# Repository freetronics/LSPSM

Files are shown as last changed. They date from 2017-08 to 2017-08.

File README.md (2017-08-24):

Freetronics LibreSat Power Supply Module
========================================
Copyright 2013 Freetronics Pty Ltd  
Freetronics site:  www.freetronics.com.au  
Freetronics email: info@freetronics.com.au  

FIXME

Features:

 * FIXME

More information is available at:

  http://www.freetronics.com.au/lspsm

INSTALLATION
------------
The design is saved as an EAGLE project. EAGLE PCB design software is
available from www.cadsoftusa.com free for non-commercial use. To use
this project download it and place the directory containing these files
into the "eagle" directory on your computer. Then open EAGLE and
navigate to the project.

DISTRIBUTION
------------
The specific terms of distribution of this project are governed by the
license referenced below.

LICENSE
-------
Licensed under the TAPR Open Hardware License (www.tapr.org/OHL).
The "license" folder within this repository also contains a copy of
this license in plain text format.

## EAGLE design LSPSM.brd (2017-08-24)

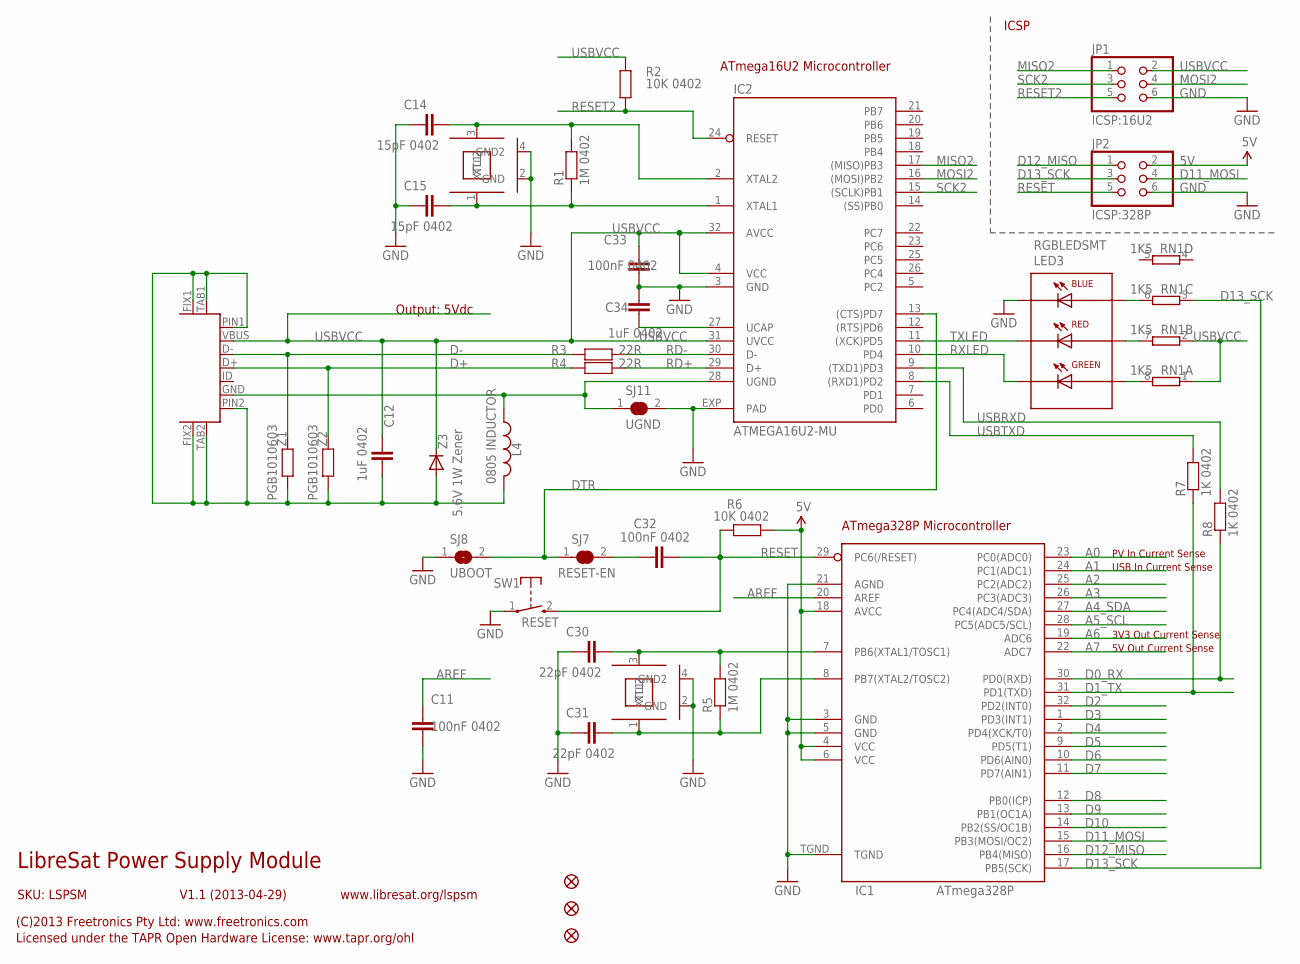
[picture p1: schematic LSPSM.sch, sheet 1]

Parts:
C11, C32, C33: 100nF 0402; 0402C
C12, C34: 1uF 0402; 0402C
C14, C15: 15pF 0402; 0402C
C30, C31: 22pF 0402; 0402C
FID1, FID2, FID3: FIDUCIAL1X2.5; FIDUCIAL-1X2.5
IC1: ATmega328P; MLF32
IC2: ATMEGA16U2-MU; ATMEL_QFN32
JP1: ICSP:16U2; 2X03
JP2: ICSP:328P; 2X03
L4: 0805 INDUCTOR; 0805-LARGE
LED3: RGBLEDSMT; 19-337
R1, R5: 1M 0402; 0402
R2, R6: 10K 0402; 0402
R3, R4: 22R; 0402
R7, R8: 1K 0402; 0402
RN1: 1K5; CAY16
S1: USB-6PSMT; USB-MICROB-MB05PMXX
SJ7: RESET-EN; 0402SJC
SJ8: UBOOT; 0402SJO
SJ11: UGND; 0402SJC
SW1: RESET; TACTILE_SWITCH_SMD_2PIN_TINY
XTL1, XTL2: 16MHz; CRYSTAL-SMD-3X2
Z1, Z2: PGB1010603; 0603
Z3: 5.6V 1W Zener; SMA-DIODE

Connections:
5V: IC1.4 (VCC), IC1.6 (VCC), IC1.18 (AVCC), JP2.2, R6.2; also elsewhere on the board
A0: IC1.23 (PC0(ADC0)); also elsewhere on the board
A1: IC1.24 (PC1(ADC1)); also elsewhere on the board
A2: IC1.25 (PC2(ADC2)); also elsewhere on the board
A3: IC1.26 (PC3(ADC3)); also elsewhere on the board
A4_SDA: IC1.27 (PC4(ADC4/SDA)); also elsewhere on the board
A5_SCL: IC1.28 (PC5(ADC5/SCL)); also elsewhere on the board
A6: IC1.19 (ADC6); also elsewhere on the board
A7: IC1.22 (ADC7); also elsewhere on the board
AREF: C11.1, IC1.20 (AREF); also elsewhere on the board
D0_RX: IC1.30 (PD0(RXD)), R8.1; also elsewhere on the board
D1_TX: IC1.31 (PD1(TXD)), R7.1; also elsewhere on the board
D2: IC1.32 (PD2(INT0)); also elsewhere on the board
D3: IC1.1 (PD3(INT1)); also elsewhere on the board
D4: IC1.2 (PD4(XCK/T0)); also elsewhere on the board
D5: IC1.9 (PD5(T1)); also elsewhere on the board
D6: IC1.10 (PD6(AIN0)); also elsewhere on the board
D7: IC1.11 (PD7(AIN1)); also elsewhere on the board
D8: IC1.12 (PB0(ICP)); also elsewhere on the board
D9: IC1.13 (PB1(OC1A)); also elsewhere on the board
D10: IC1.14 (PB2(SS/OC1B)); also elsewhere on the board
D11_MOSI: IC1.15 (PB3(MOSI/OC2)), JP2.4; also elsewhere on the board
D12_MISO: IC1.16 (PB4(MISO)), JP2.1; also elsewhere on the board
D13_SCK: IC1.17 (PB5(SCK)), JP2.3, RN1.3 (1); also elsewhere on the board
D+: R4.1, S1.D+, Z2.2
D-: R3.1, S1.D-, Z1.2
DTR: IC2.13 ((CTS)PD7), SJ7.1, SJ8.2
GND: C11.2, C14.1, C15.1, C30.1, C31.1, C33.2, C34.2, IC1.3 (GND), IC1.5 (GND), IC1.21 (AGND), IC1.TGND, IC2.3 (GND), IC2.EXP (PAD), JP1.6, JP2.6, LED3.1 (C-B), SJ8.1, SJ11.2, SW1.1, XTL1.2 (GND), XTL1.4 (GND2), XTL2.2 (GND), XTL2.4 (GND2); also elsewhere on the board
MISO2: IC2.17 ((MISO)PB3), JP1.1
MOSI2: IC2.16 ((MOSI)PB2), JP1.4
unnamed: C30.2, IC1.7 (PB6(XTAL1/TOSC1)), R5.2, XTL2.3 (XTL2)
unnamed: C15.2, IC2.1 (XTAL1), R1.1, XTL1.1 (XTL1)
unnamed: LED3.4 (A-B), RN1.6 (2)
unnamed: LED3.5 (A-R), RN1.7 (2)
unnamed: LED3.6 (A-G), RN1.8 (2)
unnamed: C31.2, IC1.8 (PB7(XTAL2/TOSC2)), R5.1, XTL2.1 (XTL1)
unnamed: C34.1, IC2.27 (UCAP)
unnamed: C12.2, L4.2, S1.FIX1, S1.FIX2, S1.PIN1, S1.PIN2, S1.TAB1, S1.TAB2, Z1.1, Z2.1, Z3.A
unnamed: C14.2, IC2.2 (XTAL2), R1.2, XTL1.3 (XTL2)
unnamed: IC2.28 (UGND), L4.1, S1.GND, SJ11.1
unnamed: C32.1, SJ7.2
RD+: IC2.29 (D+), R4.2
RD-: IC2.30 (D-), R3.2
RESET: C32.2, IC1.29 (PC6(/RESET)), JP2.5, R6.1, SW1.2 (S); also elsewhere on the board
RESET2: IC2.24 (RESET), JP1.5, R2.1
RXLED: IC2.10 (PD4), LED3.3 (C-G)
SCK2: IC2.15 ((SCLK)PB1), JP1.3
TXLED: IC2.11 ((XCK)PD5), LED3.2 (C-R)
USBRXD: IC2.9 ((TXD1)PD3), R8.2
USBTXD: IC2.8 ((RXD1)PD2), R7.2
USBVCC: C12.1, C33.1, IC2.4 (VCC), IC2.31 (UVCC), IC2.32 (AVCC), JP1.2, R2.2, RN1.1, RN1.2 (1), S1.VBUS, Z3.C; also elsewhere on the board

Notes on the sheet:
ATmega328P Microcontroller
ATmega16U2 Microcontroller
PV In Current Sense
5V Out Current Sense
3V3 Out Current Sense
USB In Current Sense
Output: 5Vdc
LibreSat Power Supply Module
V1.1 (2013-04-29)
SKU: LSPSM
(C)2013 Freetronics Pty Ltd: www.freetronics.com
Licensed under the TAPR Open Hardware License: www.tapr.org/ohl
www.libresat.org/lspsm
ICSP

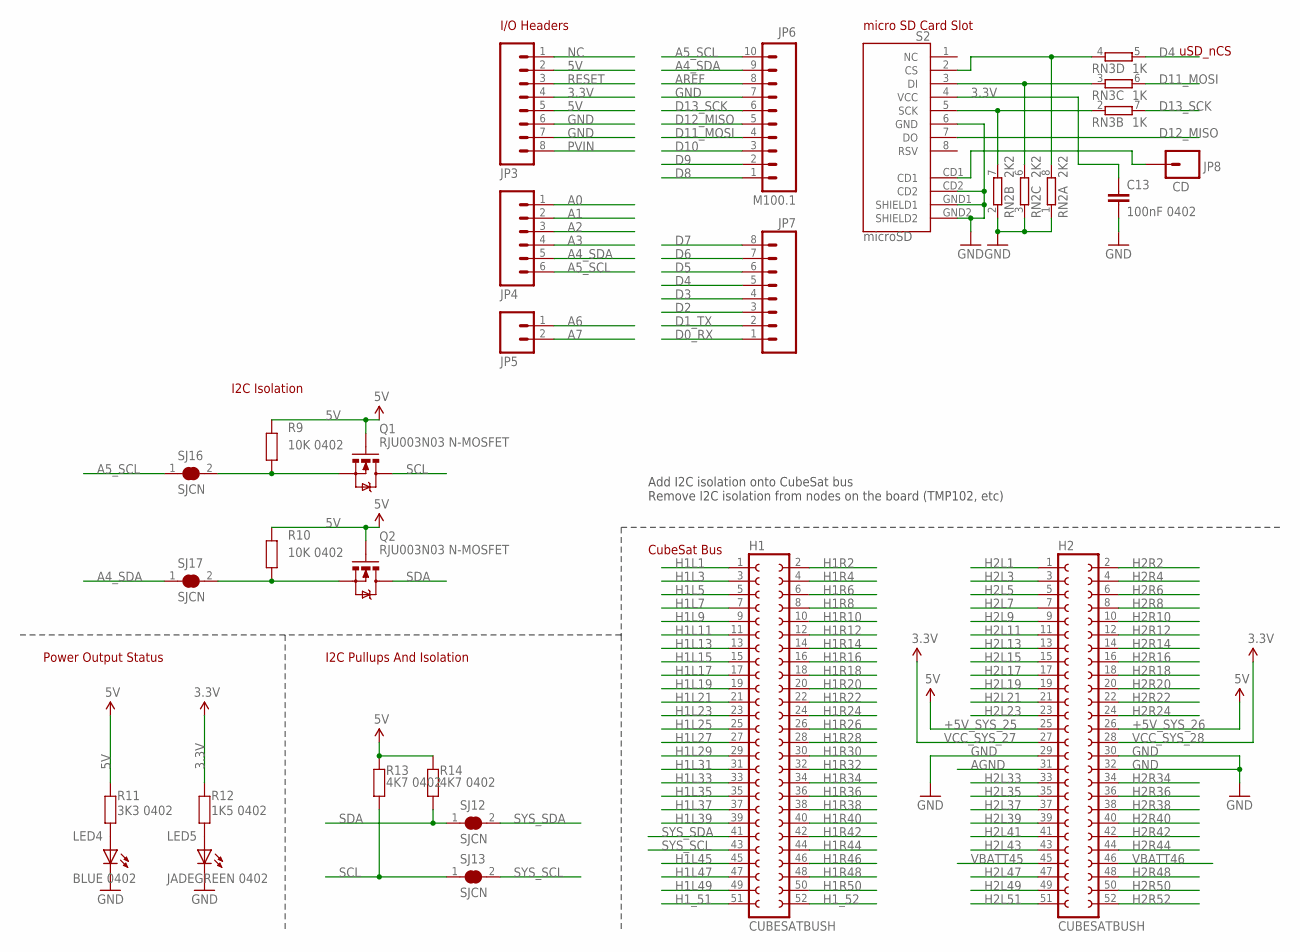
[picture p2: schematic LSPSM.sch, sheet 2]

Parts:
C13: 100nF 0402; 0402C
H1, H2: CUBESATBUSH; CUBESATBUS
JP3, JP7: M08; 1X08
JP4: M06SIP; 1X06
JP5: M02PTH; 1X02
JP6: M100.1; 1X10
JP8: CD; 1X01
LED4: BLUE 0402; LED-0402
LED5: JADEGREEN 0402; LED-0402
Q1, Q2: RJU003N03 N-MOSFET; SOT32-3
R9, R10: 10K 0402; 0402
R11: 3K3 0402; 0402
R12: 1K5 0402; 0402
R13, R14: 4K7 0402; 0402
RN2: 2K2; CAY16
RN3: 1K; CAY16
S2: microSD; MICRO-SD-SOCKET-PP
SJ12, SJ13, SJ16, SJ17: SJCN; SJC

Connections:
3.3V: C13.1, JP3.4, R12.1, S2.4 (VCC); also elsewhere on the board
5V: JP3.2, JP3.5, Q1.1 (G), Q2.1 (G), R9.2, R10.2, R11.1, R13.2, R14.2; also elsewhere on the board
+5V_SYS_25: H2.25; also elsewhere on the board
+5V_SYS_26: H2.26; also elsewhere on the board
A0: JP4.1; also elsewhere on the board
A1: JP4.2; also elsewhere on the board
A2: JP4.3; also elsewhere on the board
A3: JP4.4; also elsewhere on the board
A4_SDA: JP4.5, JP6.9, SJ17.1; also elsewhere on the board
A5_SCL: JP4.6, JP6.10, SJ16.1; also elsewhere on the board
A6: JP5.1; also elsewhere on the board
A7: JP5.2; also elsewhere on the board
AGND: H2.31
AREF: JP6.8; also elsewhere on the board
D0_RX: JP7.1; also elsewhere on the board
D1_TX: JP7.2; also elsewhere on the board
D2: JP7.3; also elsewhere on the board
D3: JP7.4; also elsewhere on the board
D4: JP7.5, RN3.5 (2); also elsewhere on the board
D5: JP7.6; also elsewhere on the board
D6: JP7.7; also elsewhere on the board
D7: JP7.8; also elsewhere on the board
D8: JP6.1; also elsewhere on the board
D9: JP6.2; also elsewhere on the board
D10: JP6.3; also elsewhere on the board
D11_MOSI: JP6.4, RN3.6 (2); also elsewhere on the board
D12_MISO: JP6.5, S2.7 (DO); also elsewhere on the board
D13_SCK: JP6.6, RN3.7 (2); also elsewhere on the board
GND: C13.2, H2.29, H2.30, H2.32, JP3.6, JP3.7, JP6.7, LED4.C, LED5.C, RN2.1, RN2.2 (1), RN2.3 (1), S2.6 (GND), S2.CD2, S2.GND1 (SHIELD1), S2.GND2 (SHIELD2); also elsewhere on the board
H1L1: H1.1
H1L3: H1.3
H1L5: H1.5
H1L7: H1.7
H1L9: H1.9
H1L11: H1.11
H1L13: H1.13
H1L15: H1.15
H1L17: H1.17
H1L19: H1.19
H1L21: H1.21
H1L23: H1.23
H1L25: H1.25
H1L27: H1.27
H1L29: H1.29
H1L31: H1.31
H1L33: H1.33
H1L35: H1.35
H1L37: H1.37
H1L39: H1.39
H1L45: H1.45
H1L47: H1.47
H1L49: H1.49
H1R2: H1.2
H1R4: H1.4
H1R6: H1.6
H1R8: H1.8
H1R10: H1.10
H1R12: H1.12
H1R14: H1.14
H1R16: H1.16
H1R18: H1.18
H1R20: H1.20
H1R22: H1.22
H1R24: H1.24
H1R26: H1.26
H1R28: H1.28
H1R30: H1.30
H1R32: H1.32
H1R34: H1.34
H1R36: H1.36
H1R38: H1.38
H1R40: H1.40
H1R42: H1.42
H1R44: H1.44
H1R46: H1.46
H1R48: H1.48
H1R50: H1.50
H1_51: H1.51
H1_52: H1.52
H2L1: H2.1
H2L3: H2.3
H2L5: H2.5
H2L7: H2.7
H2L9: H2.9
H2L11: H2.11
H2L13: H2.13
H2L15: H2.15
H2L17: H2.17
H2L19: H2.19
H2L21: H2.21
H2L23: H2.23
H2L33: H2.33
H2L35: H2.35
H2L37: H2.37
H2L39: H2.39
H2L41: H2.41
H2L43: H2.43
H2L47: H2.47
H2L49: H2.49
H2L51: H2.51
H2R2: H2.2
H2R4: H2.4
H2R6: H2.6
H2R8: H2.8
H2R10: H2.10
H2R12: H2.12
H2R14: H2.14
H2R16: H2.16
H2R18: H2.18
H2R20: H2.20
H2R22: H2.22
H2R24: H2.24
H2R34: H2.34
H2R36: H2.36
H2R38: H2.38
H2R40: H2.40
H2R42: H2.42
H2R44: H2.44
H2R48: H2.48
H2R50: H2.50
H2R52: H2.52
unnamed: LED5.A, R12.2
unnamed: LED4.A, R11.2
unnamed: RN2.8 (2), RN3.4 (1), S2.2 (CS)
unnamed: RN2.6 (2), RN3.3 (1), S2.3 (DI)
unnamed: RN2.7 (2), RN3.2 (1), S2.5 (SCK)
unnamed: JP8.1, S2.CD1
unnamed: Q1.2 (S), R9.1, SJ16.2
unnamed: Q2.2 (S), R10.1, SJ17.2
NC: JP3.1
PVIN: JP3.8; also elsewhere on the board
RESET: JP3.3; also elsewhere on the board
SCL: Q1.3 (D), R13.1, SJ13.1; also elsewhere on the board
SDA: Q2.3 (D), R14.1, SJ12.1; also elsewhere on the board
SYS_SCL: H1.43, SJ13.2
SYS_SDA: H1.41, SJ12.2
VBATT45: H2.45; also elsewhere on the board
VBATT46: H2.46; also elsewhere on the board
VCC_SYS_27: H2.27; also elsewhere on the board
VCC_SYS_28: H2.28; also elsewhere on the board

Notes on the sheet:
CubeSat Bus
Power Output Status
I2C Pullups And Isolation
uSD_nCS
micro SD Card Slot
I2C Isolation
I/O Headers
Add I2C isolation onto CubeSat bus Remove I2C isolation from nodes on the board (TMP102, etc)

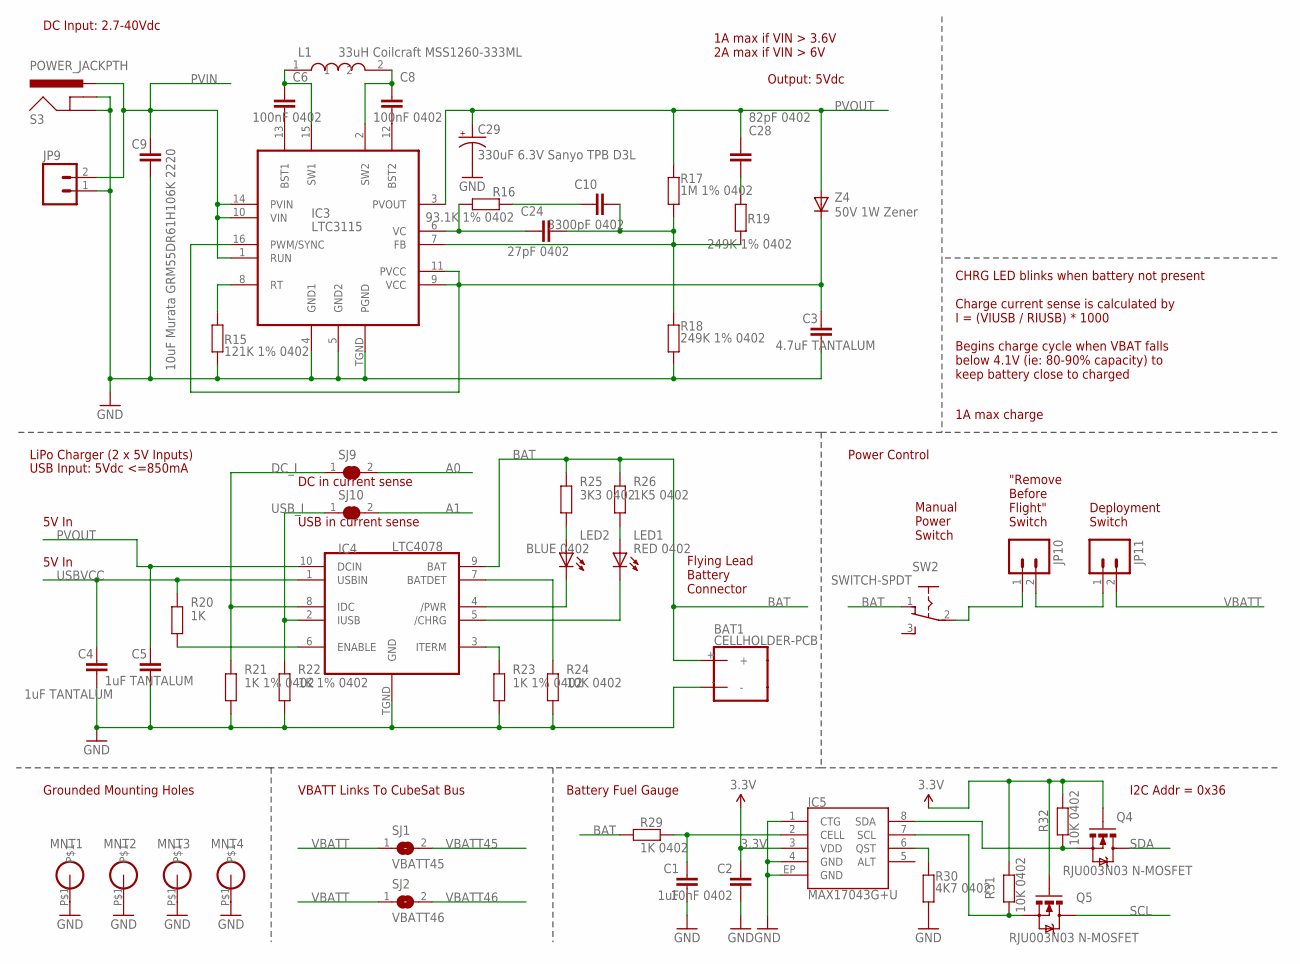
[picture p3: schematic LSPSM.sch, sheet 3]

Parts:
BAT1: CELLHOLDER-PCB; BH-18650-PC
C1: 1uF; 0402C
C2: 10nF 0402; 0402C
C3: 4.7uF TANTALUM; C1206K
C4, C5: 1uF TANTALUM; C1206K
C6, C8: 100nF 0402; 0402C
C9: 10uF Murata GRM55DR61H106K 2220; C2220K
C10: 3300pF 0402; 0402C
C24: 27pF 0402; 0402C
C28: 82pF 0402; 0402C
C29: 330uF 6.3V Sanyo TPB D3L; D3L
IC3: LTC3115; DFN-16
IC4: LTC4078; DFN-10
IC5: MAX17043G+U; TDFN-8
JP9, JP10, JP11: M02PTH; 1X02
L1: 33uH Coilcraft MSS1260-333ML; MSS1260
LED1: RED 0402; LED-0402
LED2: BLUE 0402; LED-0402
MNT1, MNT2, MNT3, MNT4: HOLE3.2MM; HOLE32
Q4, Q5: RJU003N03 N-MOSFET; SOT32-3
R15: 121K 1% 0402; 0402
R16: 93.1K 1% 0402; 0402
R17: 1M 1% 0402; 0402
R18, R19: 249K 1% 0402; 0402
R20: 1K; 0402
R21, R22, R23: 1K 1% 0402; 0402
R24, R31, R32: 10K 0402; 0402
R25: 3K3 0402; 0402
R26: 1K5 0402; 0402
R29: 1K 0402; 0402
R30: 4K7 0402; 0402
S3: POWER_JACKPTH; POWER_JACK_PTH
SJ1: VBATT45; SJ
SJ2: VBATT46; SJ
SJ9: DC_I; SJC
SJ10: USB_I; SJC
SW2: SWITCH-SPDT; SS-12F100
Z4: 50V 1W Zener; SMA-DIODE

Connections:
3.3V: C2.1, IC5.3 (VDD), Q4.1 (G), Q5.1 (G), R31.2, R32.2; also elsewhere on the board
A0: SJ9.2; also elsewhere on the board
A1: SJ10.2; also elsewhere on the board
BAT: BAT1.+, IC4.9 (BAT), R25.1, R26.1, R29.2, SW2.1
CELL: C1.1, IC5.2 (CELL), R29.1
DC_I: IC4.8 (IDC), R21.1, SJ9.1
GND: BAT1.-, C1.2, C2.2, C3.1, C4.1, C5.1, C9.1, C29.NEG (-), IC3.4 (GND1), IC3.5 (GND2), IC3.TGND (PGND), IC4.TGND (GND), IC5.1 (CTG), IC5.4 (GND), IC5.EP (GND), JP9.1, MNT1.P$1, MNT2.P$1, MNT3.P$1, MNT4.P$1, R15.1, R18.1, R21.2, R22.2, R23.2, R24.2, R30.1, S3.GND, S3.GNDBREAK; also elsewhere on the board
unnamed: JP10.2, JP11.1
unnamed: LED2.A, R25.2
unnamed: JP10.1, SW2.2
unnamed: IC5.8 (SDA), Q4.2 (S), R32.1
unnamed: IC5.7 (SCL), Q5.2 (S), R31.1
unnamed: IC4.7 (BATDET), R24.1
unnamed: IC4.4 (/PWR), LED2.C
unnamed: IC4.3 (ITERM), R23.1
unnamed: IC4.6 (ENABLE), R20.2
unnamed: C10.1, R16.2
unnamed: C3.2, IC3.9 (VCC), IC3.11 (PVCC), IC3.16 (PWM/SYNC), Z4.C
unnamed: C6.2, IC3.13 (BST1)
unnamed: C8.2, IC3.12 (BST2)
unnamed: C6.1, IC3.15 (SW1), L1.1
unnamed: C8.1, IC3.2 (SW2), L1.2
unnamed: C24.1, IC3.6 (VC), R16.1
unnamed: C10.2, C24.2, IC3.7 (FB), R17.1, R18.2, R19.1
unnamed: IC3.8 (RT), R15.2
unnamed: C28.2, R19.2
unnamed: LED1.A, R26.2
unnamed: IC4.5 (/CHRG), LED1.C
PVIN: C9.2, IC3.1 (RUN), IC3.10 (VIN), IC3.14 (PVIN), JP9.2, S3.PWR; also elsewhere on the board
PVOUT: C5.2, C28.1, C29.POS (+), IC3.3 (PVOUT), IC4.10 (DCIN), R17.2, Z4.A
QST: IC5.6 (QST), R30.2
SCL: Q5.3 (D); also elsewhere on the board
SDA: Q4.3 (D); also elsewhere on the board
USBVCC: C4.2, IC4.1 (USBIN), R20.1; also elsewhere on the board
USB_I: IC4.2 (IUSB), R22.1, SJ10.1
VBATT: JP11.2, SJ1.1, SJ2.1; also elsewhere on the board
VBATT45: SJ1.2; also elsewhere on the board
VBATT46: SJ2.2; also elsewhere on the board

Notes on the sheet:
LiPo Charger (2 x 5V Inputs)
I2C Addr = 0x36
"Remove Before Flight" Switch
Deployment Switch
Manual Power Switch
Flying Lead Battery Connector
CHRG LED blinks when battery not present Charge current sense is calculated by I = (VIUSB / RIUSB) * 1000 Begins charge cycle when VBAT falls below 4.1V (ie: 80-90% capacity) to keep battery close to charged
1A max charge
DC in current sense
USB in current sense
1A max if VIN > 3.6V 2A max if VIN > 6V
DC Input: 2.7-40Vdc
Grounded Mounting Holes
VBATT Links To CubeSat Bus
Battery Fuel Gauge
Power Control
Output: 5Vdc
5V In
USB Input: 5Vdc <=850mA

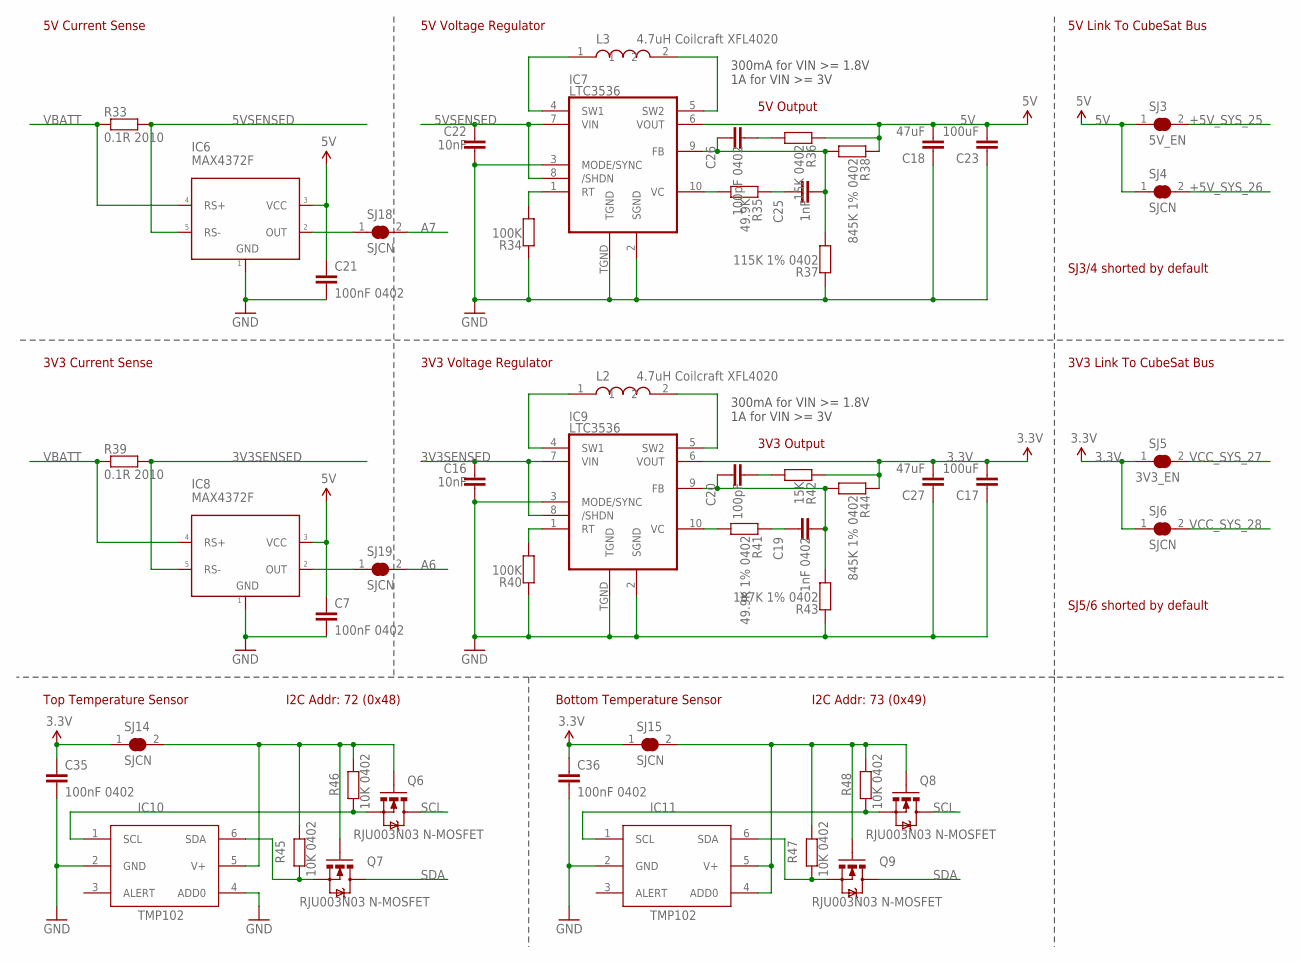
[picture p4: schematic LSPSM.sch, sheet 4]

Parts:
C7, C21, C35, C36: 100nF 0402; 0402C
C16, C22: 10nF; 0402C
C17, C23: 100uF; C1206K
C18, C27: 47uF; C1206K
C19: 1nF 0402; 0402C
C20: 100pF; 0402C
C25: 1nF; 0402C
C26: 100pF 0402; 0402C
IC6, IC8: MAX4372F; SOT23-5
IC7, IC9: LTC3536; DFN-10
IC10, IC11: TMP102; SOT563
L2, L3: 4.7uH Coilcraft XFL4020; XFL4020
Q6, Q7, Q8, Q9: RJU003N03 N-MOSFET; SOT32-3
R33, R39: 0.1R 2010; R2010
R34, R40: 100K; 0402
R35: 49.9K; 0402
R36: 15K 0402; 0402
R37: 115K 1% 0402; 0402
R38, R44: 845K 1% 0402; 0402
R41: 49.9K 1% 0402; 0402
R42: 15K; 0402
R43: 187K 1% 0402; 0402
R45, R46, R47, R48: 10K 0402; 0402
SJ3: 5V_EN; SJC
SJ4, SJ6, SJ14, SJ15, SJ18, SJ19: SJCN; SJC
SJ5: 3V3_EN; SJC

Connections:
3.3V: C17.2, C27.2, C35.1, C36.1, IC9.6 (VOUT), R42.2, R44.2, SJ5.1, SJ6.1, SJ14.1, SJ15.1; also elsewhere on the board
3V3SENSED: C16.1, IC8.5 (RS-), IC9.7 (VIN), IC9.8 (/SHDN), R39.2
5V: C7.1, C18.2, C21.1, C23.2, IC6.3 (VCC), IC7.6 (VOUT), IC8.3 (VCC), R36.2, R38.2, SJ3.1, SJ4.1; also elsewhere on the board
5VSENSED: C22.1, IC6.5 (RS-), IC7.7 (VIN), IC7.8 (/SHDN), R33.2
+5V_SYS_25: SJ3.2; also elsewhere on the board
+5V_SYS_26: SJ4.2; also elsewhere on the board
A6: SJ19.2; also elsewhere on the board
A7: SJ18.2; also elsewhere on the board
GND: C7.2, C16.2, C17.1, C18.1, C21.2, C22.2, C23.1, C27.1, C35.2, C36.2, IC6.1 (GND), IC7.2 (SGND), IC7.3 (MODE/SYNC), IC7.TGND, IC8.1 (GND), IC9.2 (SGND), IC9.3 (MODE/SYNC), IC9.TGND, IC10.2 (GND), IC10.4 (ADD0), IC11.2 (GND), R34.2, R37.2, R40.2, R43.2; also elsewhere on the board
unnamed: IC6.2 (OUT), SJ18.1
unnamed: IC9.10 (VC), R41.1
unnamed: IC9.4 (SW1), L2.1
unnamed: IC9.5 (SW2), L2.2
unnamed: IC9.1 (RT), R40.1
unnamed: IC7.4 (SW1), L3.1
unnamed: C19.1, R41.2
unnamed: C20.2, R42.1
unnamed: C19.2, C20.1, IC9.9 (FB), R43.1, R44.1
unnamed: IC7.5 (SW2), L3.2
unnamed: IC7.1 (RT), R34.1
unnamed: C25.1, R35.2
unnamed: IC7.10 (VC), R35.1
unnamed: C26.2, R36.1
unnamed: C25.2, C26.1, IC7.9 (FB), R37.1, R38.1
unnamed: IC8.2 (OUT), SJ19.1
unnamed: IC10.5 (V+), Q6.1 (G), Q7.1 (G), R45.2, R46.2, SJ14.2
unnamed: IC11.4 (ADD0), IC11.5 (V+), Q8.1 (G), Q9.1 (G), R47.2, R48.2, SJ15.2
unnamed: IC10.1 (SCL), Q6.2 (S), R46.1
unnamed: IC10.6 (SDA), Q7.2 (S), R45.1
unnamed: IC11.6 (SDA), Q9.2 (S), R47.1
unnamed: IC11.1 (SCL), Q8.2 (S), R48.1
SCL: Q6.3 (D), Q8.3 (D); also elsewhere on the board
SDA: Q7.3 (D), Q9.3 (D); also elsewhere on the board
VBATT: IC6.4 (RS+), IC8.4 (RS+), R33.1, R39.1; also elsewhere on the board
VCC_SYS_27: SJ5.2; also elsewhere on the board
VCC_SYS_28: SJ6.2; also elsewhere on the board

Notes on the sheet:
5V Link To CubeSat Bus
3V3 Output
5V Output
5V Current Sense
300mA for VIN >= 1.8V 1A for VIN >= 3V
3V3 Link To CubeSat Bus
5V Voltage Regulator
3V3 Current Sense
3V3 Voltage Regulator
Top Temperature Sensor
I2C Addr: 72 (0x48)
Bottom Temperature Sensor
I2C Addr: 73 (0x49)
SJ3/4 shorted by default
SJ5/6 shorted by default

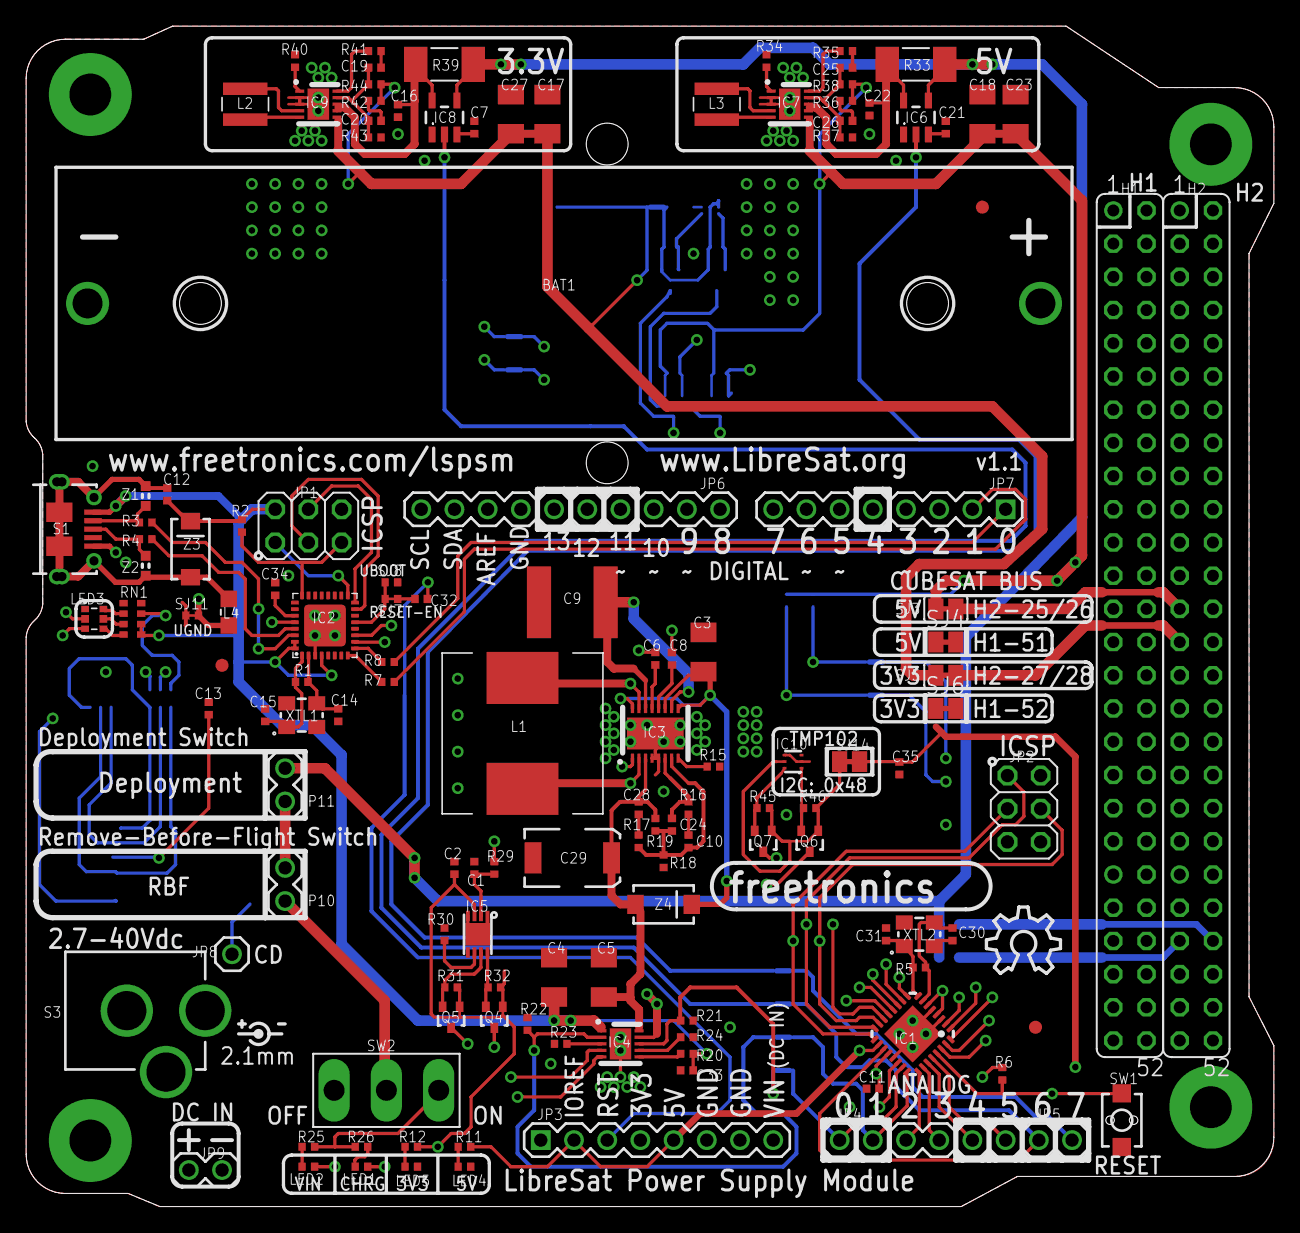
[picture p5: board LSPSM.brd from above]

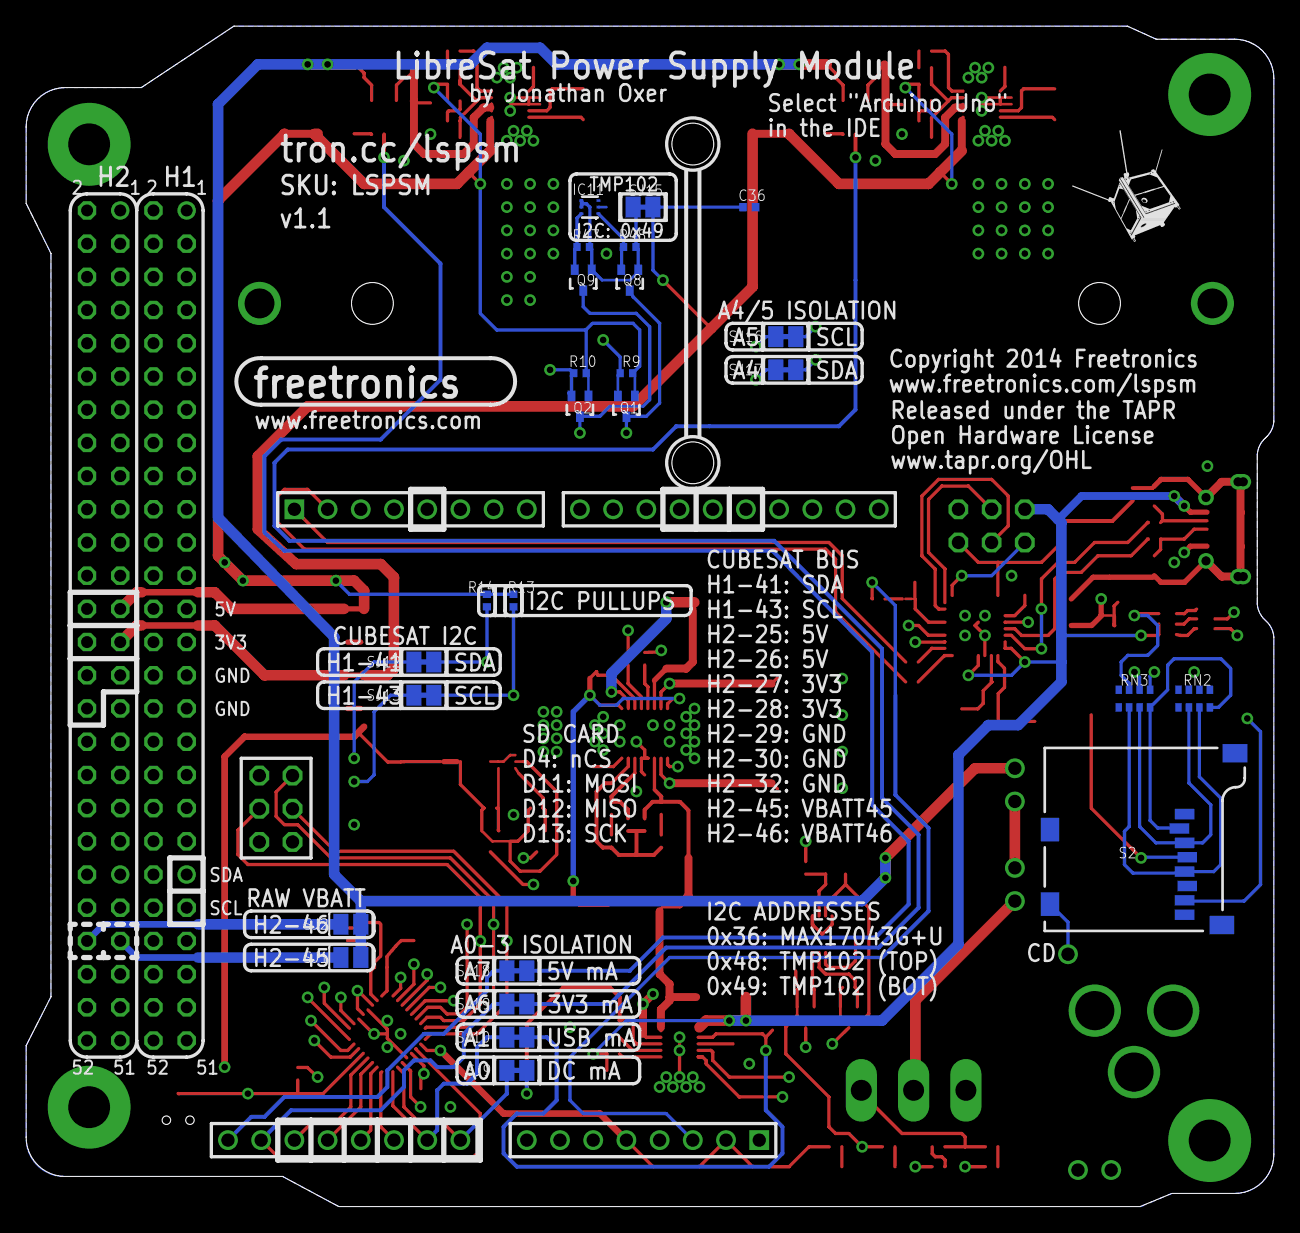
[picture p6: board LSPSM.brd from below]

Board: 4 copper layers, 95.5 x 90.3 mm, 165 parts (26 on the bottom side), 123 nets.

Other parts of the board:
U$2: OSHW_10X200_NOTEXT

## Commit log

2012-12-19 Initial project import
    [ArduSatPowerSupplyModule.brd, ArduSatPowerSupplyModule.sch]
2012-12-19 Completed routing
    [ArduSatPowerSupplyModule.brd, ArduSatPowerSupplyModule.sch]
2012-12-20 Linked I2C with CubeSat bus; clearance and overlay improvements
    [ArduSatPowerSupplyModule.brd, ArduSatPowerSupplyModule.sch]
2012-12-20 Added optional I2C pull-ups on CubeSat bus side of the isolators. Changed polygon isolation to 0.012 on inner layers, 0.010 on outer. Improved spacing.
    [ArduSatPowerSupplyModule.brd, ArduSatPowerSupplyModule.sch]
2012-12-26 Added NanoSatisfi and ArduSat logos; clearances; DRC
    [ArduSatPowerSupplyModule.sch]
2012-12-28 Moved 3.3V power supply input to before the 5V current sense resistor
    [ArduSatPowerSupplyModule.sch]
2013-01-17 Routing, DRC, overlay
    [ArduSatPowerSupplyModule.sch]
2013-04-24 Totally restructured project: single 18650 cell; 0402 parts; shield footprint; dual MCUs in Eleven architecture
    [ArduSatPowerSupplyModule.brd, ArduSatPowerSupplyModule.sch]
2013-04-28 Routing done, clearances, DRC, overlay. Nearly ready for v1.0 release
    [ArduSatPowerSupplyModule.brd, ArduSatPowerSupplyModule.sch]
2013-12-17 Changed max charge rate to 1A; removed solder jumpers for ArduSat power pins
    [ArduSatPowerSupplyModule.brd, ArduSatPowerSupplyModule.sch]
2013-12-17 Changed current sense chip VCC to 5V
    [ArduSatPowerSupplyModule.brd, ArduSatPowerSupplyModule.sch]
2017-08-24 Relabelled board from ArduSat to LibreSat
    [ArduSatPowerSupplyModule.brd, ArduSatPowerSupplyModule.sch]
2017-08-24 Renamed board files from ArduSat to LibreSat
    [LSPSM.brd, LSPSM.sch]
2017-08-24 Removed ArduSat logo from silkscreen
    [LSPSM.brd, LSPSM.sch]

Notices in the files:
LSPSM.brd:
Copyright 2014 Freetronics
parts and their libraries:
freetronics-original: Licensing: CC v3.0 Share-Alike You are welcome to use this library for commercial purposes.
